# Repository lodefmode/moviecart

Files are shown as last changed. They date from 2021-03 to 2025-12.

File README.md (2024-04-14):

# moviecart
Software and Hardware to create full length color movie + audio cartridges for stock Atari 2600

[How to watch different files:](docs/How_To_Update_Content.txt)

[How to encode your own:](https://www.youtube.com/watch?v=WSy6kNrYDSo&list=PLHJZWs7or3edcvVHDeNzGSZABx2JN1WZH)

Pre-Order Kits at:

https://www.tindie.com/products/lodefmode/moviecart-atari-2600/

September 11 1977
-

Introducing MovieCart.

This revolutionary new product will allow for the first time ever, anyone to experience the joy of the silver screen directly from the comfort of their own home, in stunning digital accuracy.
Boasting an impressive 80 x 192 resolution, 7 bit color and 4 bit monaural audio, begin building your full length feature film library today.*

Technical Specs:

   Two fields are alternated at 60 frames per second.
   Each field consists of a checkerboard pattern of 10 x 262 cells.
   Each cell contains one of 128 colours and is 8 pixels wide by 1 pixel deep.
   This produces an effective resolution of 80 x 262 @ 30 frames per second, with 10 colors per line.
   
   Sound is 4 bit mono produced at 15.720 KHz.

   Joystick controls brightness, volume, and shuttle position.
   Console switches control b/w, ten second rewind and full rewind.

   Each field requires 2.5K of data.
   Each second requires the equivalent of 75.5 Combat cartridges, or over half a million cartridges to produce a full length 2 hour movie.

Thanks,

lodef.mode@gmail.com

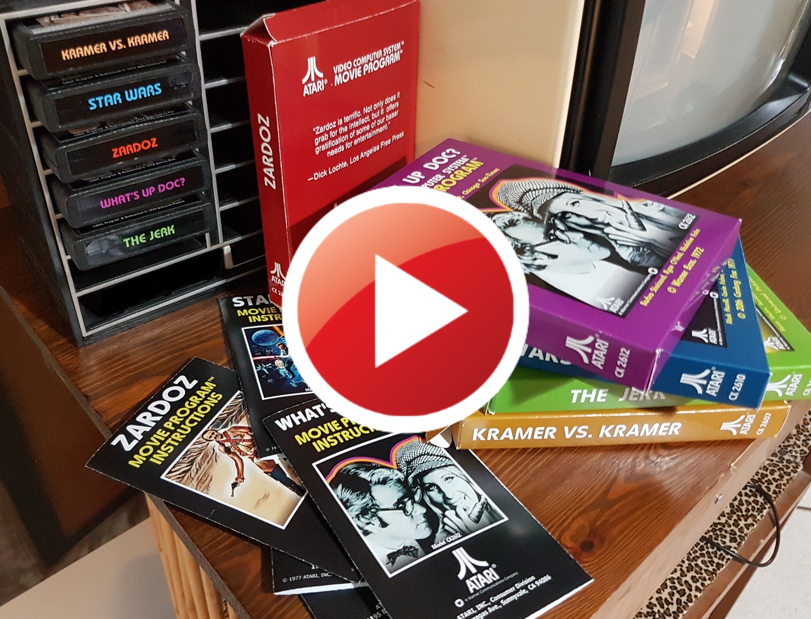
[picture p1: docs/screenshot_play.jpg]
Video (https://www.youtube.com/watch?v=PMp-7_ekibU)


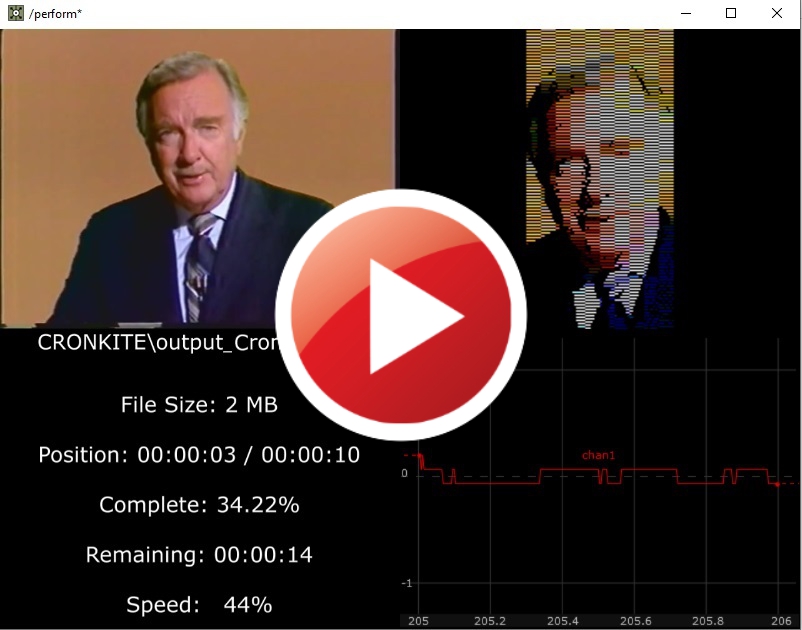
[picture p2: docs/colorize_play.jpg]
Video (https://youtu.be/7HMz1SYGolY)


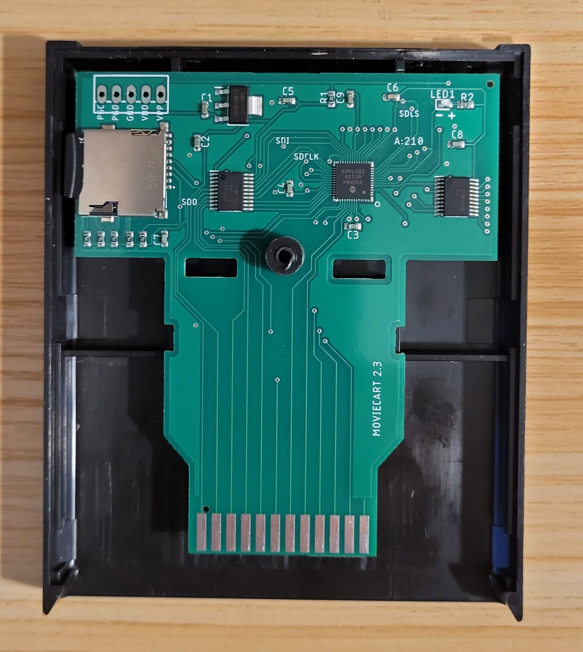
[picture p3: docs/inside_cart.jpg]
Cart

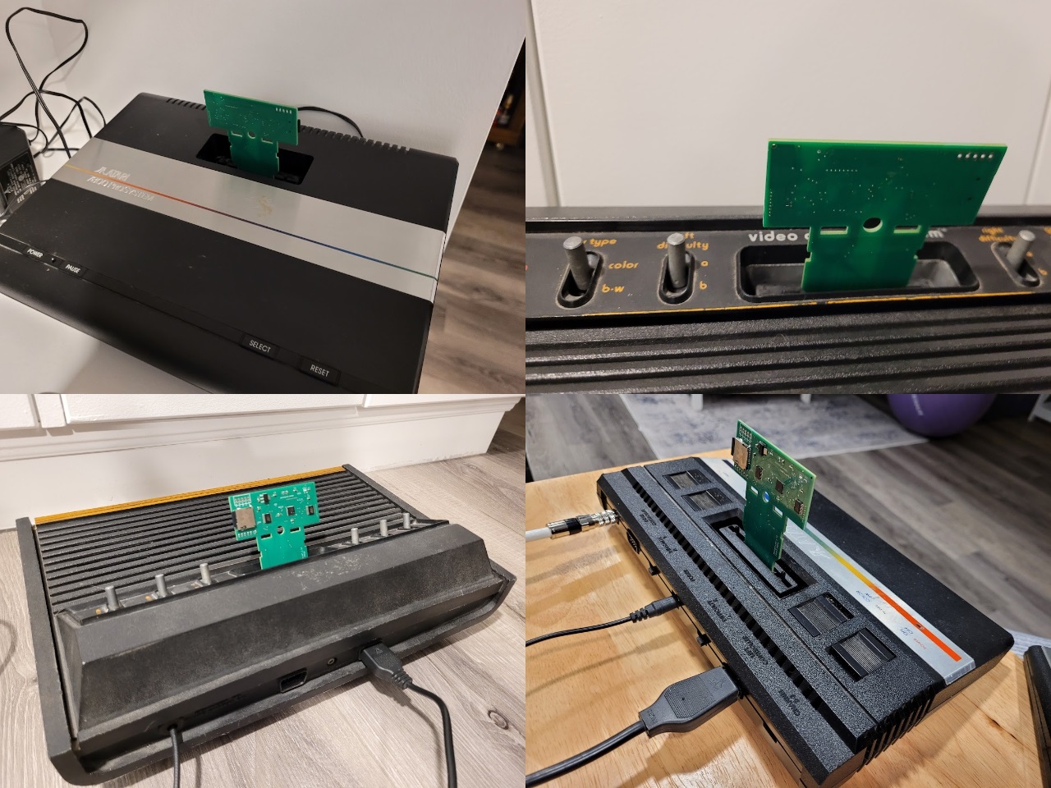
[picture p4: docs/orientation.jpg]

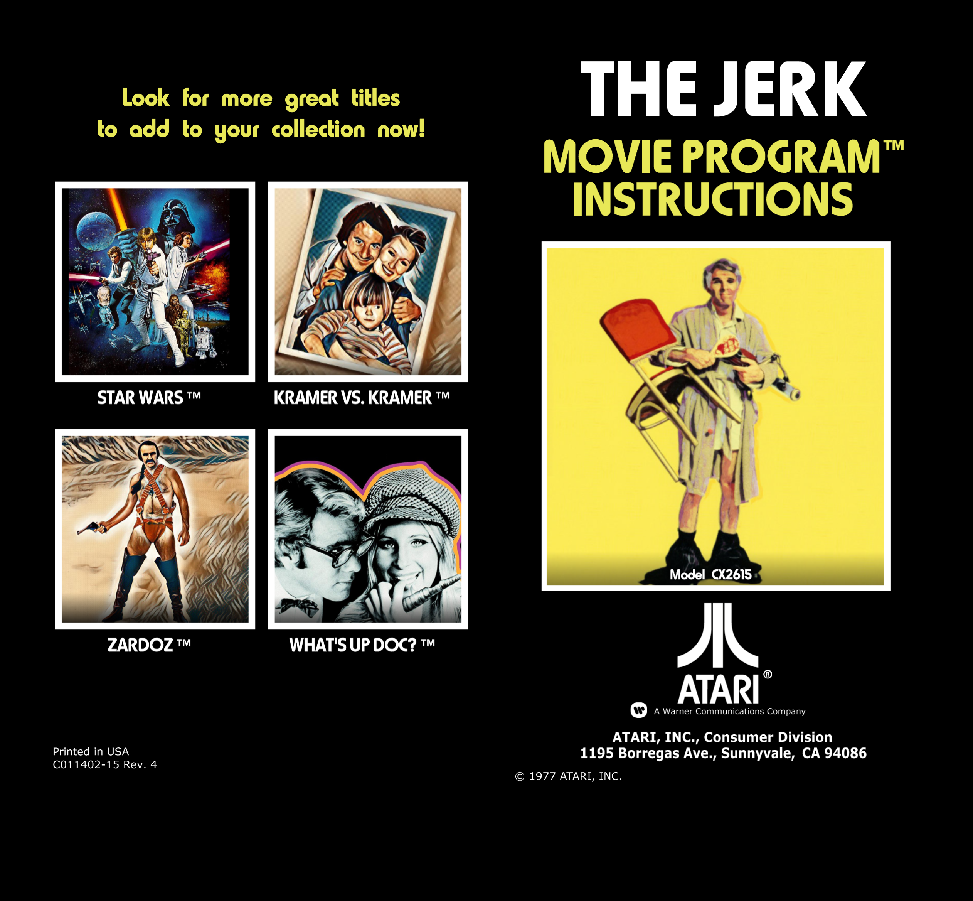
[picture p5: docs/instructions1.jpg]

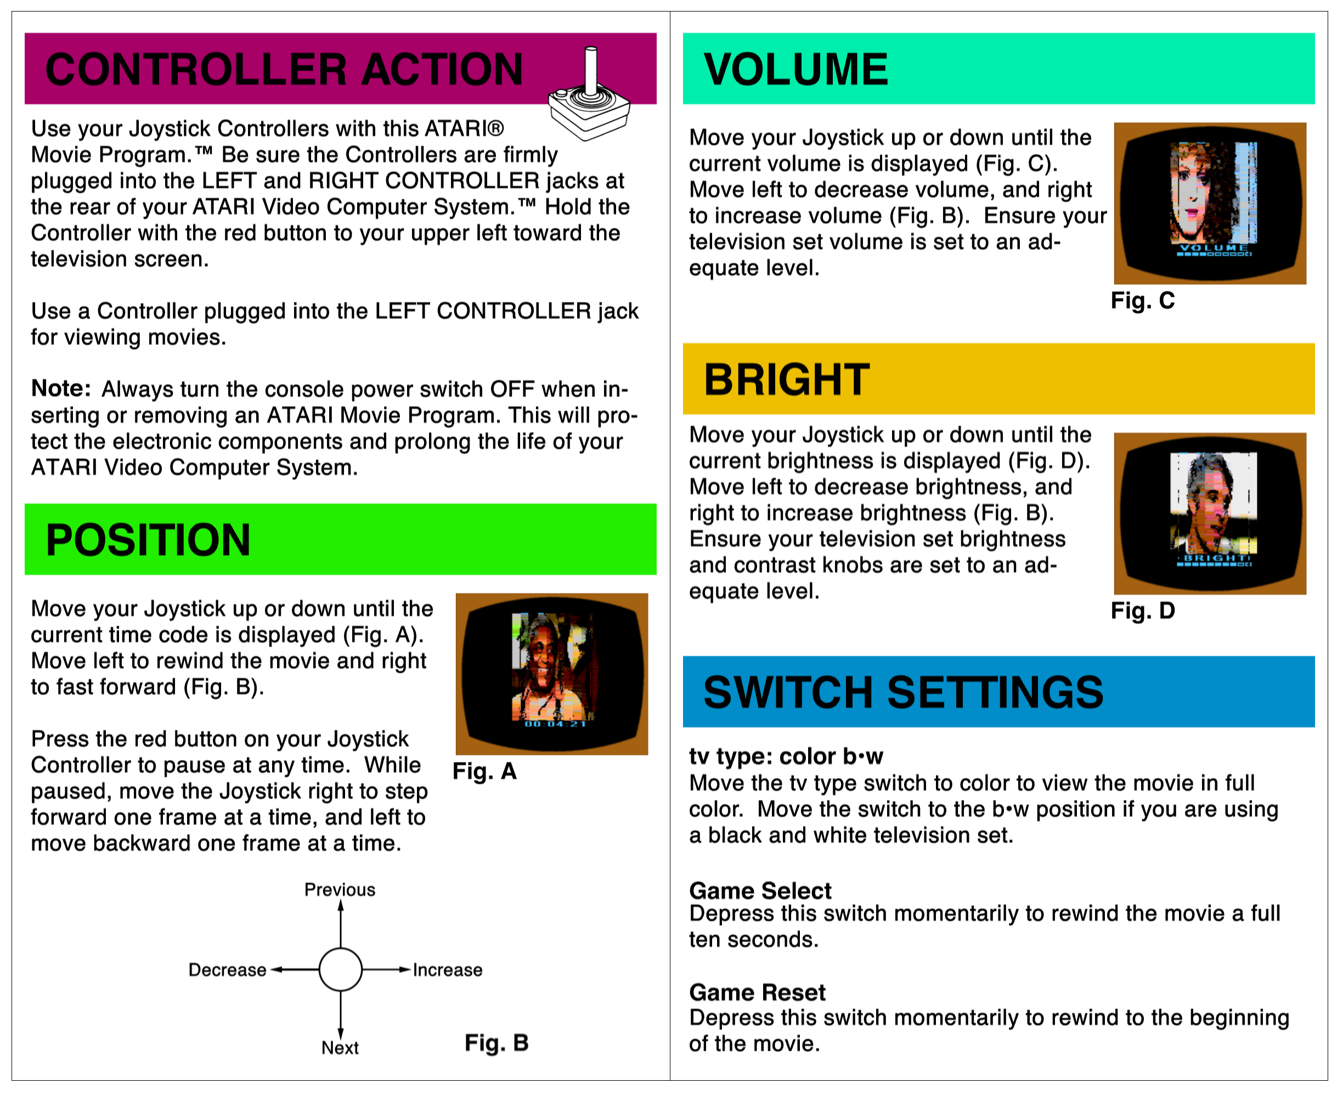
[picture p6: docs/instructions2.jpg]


*Copyright Disclaimer under Section 107 of the copyright act 1976, allowance is made for fair use for purposes such as criticism, comment, news reporting, scholarship, and research. Fair use is a use permitted by copyright statute that might otherwise be infringing. Non-profit, educational or personal use tips the balance in favour of fair use."

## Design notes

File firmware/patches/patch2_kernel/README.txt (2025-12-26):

* WARNING *

This patch is permanent.
And only applies to early MovieCarts (version 1.x from December 2024 and earlier))

Make sure power is not interrupted while the patch is being applied.
This patch fixes writes to ROM as well as being 7800 PAL startup compatible.
It also plays all mvc files sequentially on the SD card automatically, plus other small improvements.

Intstructions:

Note: This requires 2 steps:

Step 1:
With the power off, insert the moviecart with the SD card containing update.frm into the Atari.
Power up the Atari.  If successful the red LED (if visible) on the Moviecart board will flash 2,2  2,2  2,2 etc
(flash flash....pause....flash flash....pause...flash flash... etc)
It should only take a few seconds.

Step 2:
Turn off the Atari
*** REMOVE the SD card, and put it away ***
Turn the Atari back on again.
The LED will now flash 4..4..4..
It should only take a few seconds.

Turn it off and on again. 
Any subsequent powerup will be running the new firmware.
You should see a new title screen with version 2.4 or later.

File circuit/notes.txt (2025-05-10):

Each folder contains a PCB centered around a different package of dsPIC33CK64MC105.
They are otherwise identical.
Note that dsPIC33CK32MC105 is also a suitable drop in replacment at half the program size.

48_TQFP_7x7:
	DSPIC33CK32MC105-I/PT

48_UQFN_6x6:
	DSPIC33CK64MC105-I/M4

Todo:

2.31 
Central hole size:
Still too narrow on some production runs, as drill tolerance varies.
Try increasing slightly.

17/64" drill bit fits perfectly.
3.3734375 mm radius?

currently its:
3.190mm (was 3.175mm)

Around 0.18 mm increase each side.

2.32/2.42:
  hole size increased from 3.19 to 3.373

-----------------

SIKOR version:

Missing 'TV/LABEL SIDE'

special sdcard access version for injection molded offerings:
 -consider moving sd card further to edge to increase access on slotted cart.
   even widen entire top half left/right to reach edge.
 -deepen side tabs toward center to fit
 -consider shortening center post hole to match?
 -consider a double tab piece that glues through rectangular slots for stability.

consider:
  tactile switch to burn/factory reset firmware updates, instead of grounding programming pins

LED is way too bright

Octob 5 2024:

2.42:  change name to 2.52  (2.42 is P/T version)
a couple of vias are too close to paths:
  top left corner of IC, c6

2.52SD
  close vias fixed
  2.52
  'TV SIDE'
  deeper tabs
  SD moved to left edge
  tactile switch to factory reset / restore  (grounding programming pins still works)

2.5SK

  Reshaped for SIKOR carts (5 alignment holes)

2.6SK

  RT3301 reverse mounted factory reset button

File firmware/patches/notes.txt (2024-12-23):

**
** ONLY DO THIS IF ABSOLUTELY NECESSARY AS YOU RISK BRICKING THE MOVIECART **
**

-----------------------------------
INSTALLING A NEW PATCH:
-----------------------------------

Note: Installing a patch will replace any existing patches, so make sure you have the latest.
Select the update.frm file you require and place it on an sd-card by itself with no other files.
Follow the installation instructions in the associated README.txt file for that patch.

-----------------------------------
FACTORY RESET (Remove patch) :
-----------------------------------

* NOTE *  Only some patches are removable, some are permanent.
Please read the notes associated with each patch before applying.

If a patch needs to be removed, use a thin wire with both ends exposed.
A metallic sandwich twist tie, with the paper removed from each end works well.

Remove any SD cards from the MovieCart PCB.
Insert one end through the hole labelled 'PGD' and the other through the hole labelled 'GND'.
These are holes 2 and 3 of a five hole section in the upper left hand side of the MovieCart PCB.
Verify they are labelled 'PGD' and 'GND'.
Verify the ends of the wire aren't making contact with any other points on the PCB.

Insert the MovieCart PCB (with the wire in place) into the Atari, and power up the Atari.
After f;ctory reset, the red LED on the moviecart board will flash the sequence 22..22..22..
(Twice, twice, pause, twice, twice, pause, etc).

Turn off the Atari and remove the wire.
It should now power up as originally delivered.

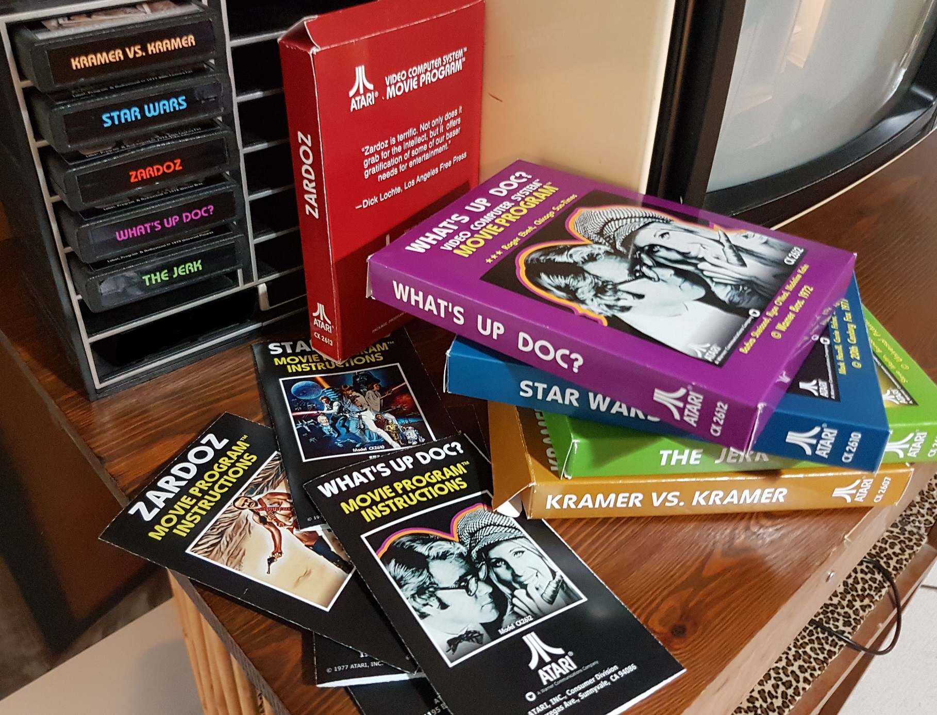
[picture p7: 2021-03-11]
docs/screenshot.jpg

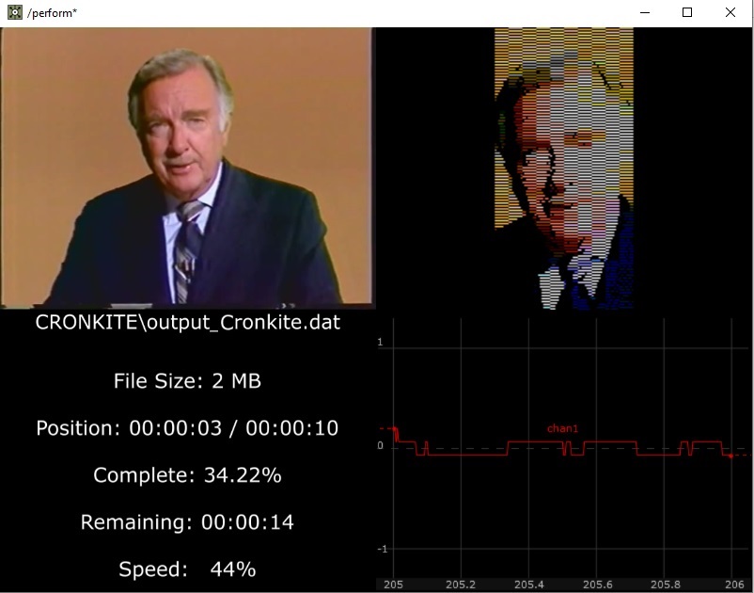
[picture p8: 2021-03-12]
docs/colorize.jpg

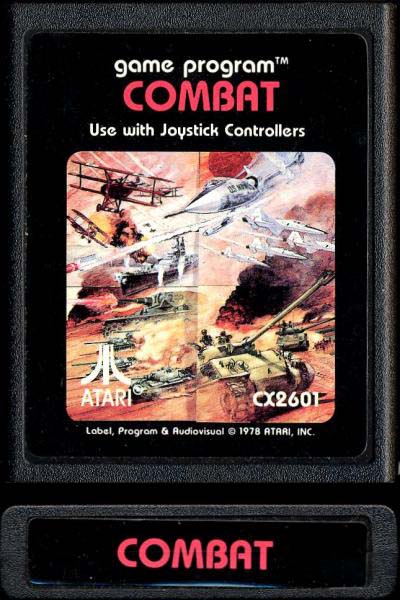
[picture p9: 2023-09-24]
label/resources/combat_reference.jpg

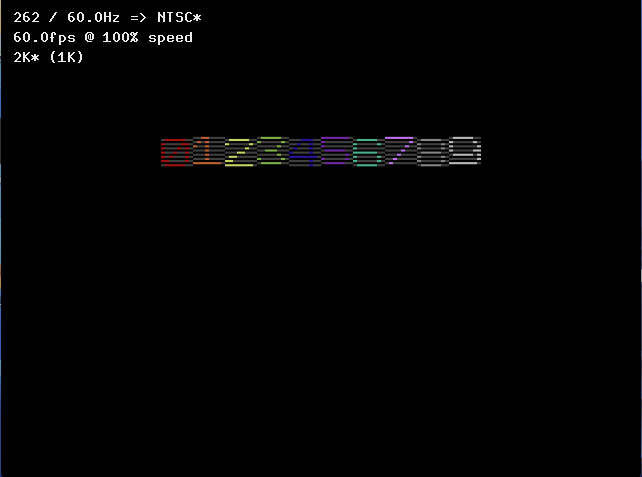
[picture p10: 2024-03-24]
kernel/movie_ntsc.png

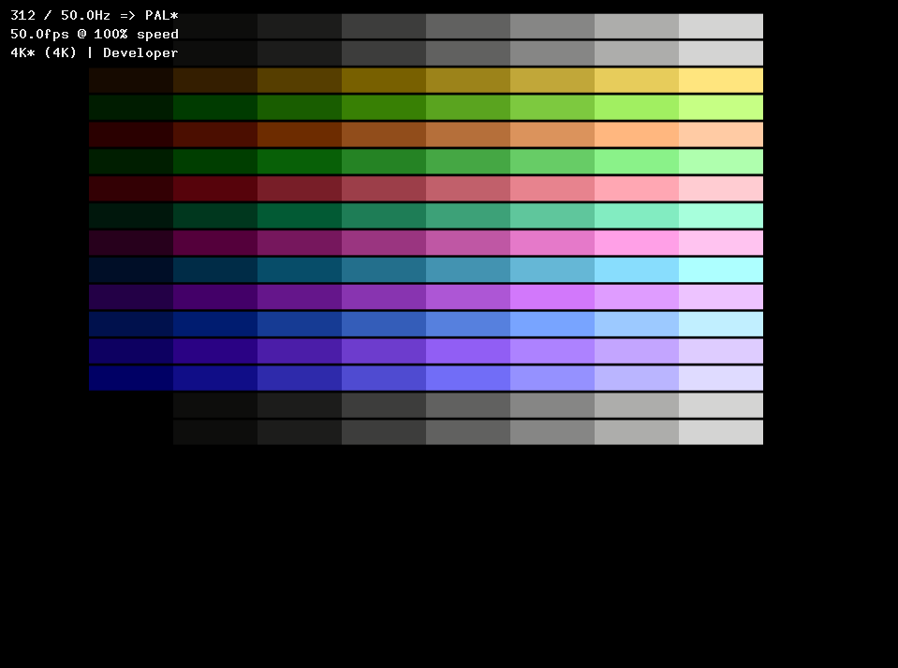
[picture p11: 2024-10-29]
kernel/color_chart/color_chart_pal.png

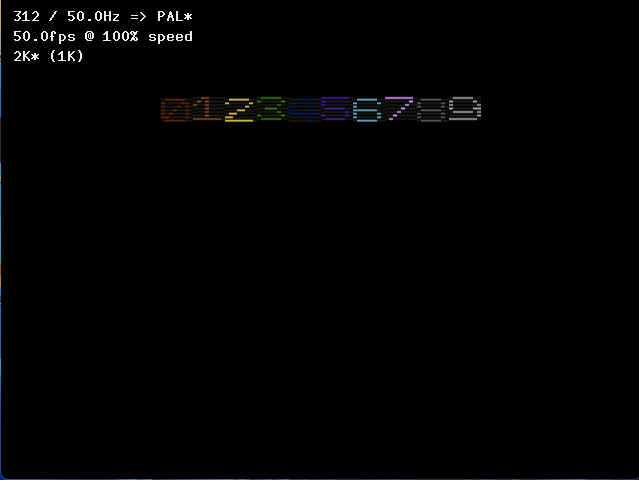
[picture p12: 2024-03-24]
kernel/movie_pal.png

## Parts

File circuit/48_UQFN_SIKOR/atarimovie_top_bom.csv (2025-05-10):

Comment | Designator | Footprint | LCSC Part #
0.1uF | C3 C4 C5 C6 C7 C8 C9 | C0603K
10K | R1 | R0603
10uF | C1 C2 | C0603K
56.2K | R3 R4 R5 R6 R7 | R0603
74LVCH245APW 118 | U2 | SOP65P640X110-20N
74LVCH245APW 118 | U3 | SOP65P640X110-20N
180Ω | R2 | R0603
AMS1117-3.3V | IC1 | SOT229P700X180-4N
CARTRIDGE EDGE | J1 | MED_TABS_SDACCESS
DSPIC33CKXXMC105-X_M4 | U1 | UQFN48_6X6MC_MCH
KT-0603R | LED1 | LEDC1608X70N
RT3301AF260Q | FACTORYRESET | RT3301_EWI
TF-15X15 | J2 | TF15X15

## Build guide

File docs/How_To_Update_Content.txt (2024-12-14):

Updating content:

Your MovieCart should include an sd-card with full length movie on it.
Feel free to put any mvc files on it, including your own.

NOTES:

Best performance is had when the sd-card is freshly formatted before placing the file,
to make forwarding and rewinding smoother.
When formatting an sd-card, it must be FAT32 format.

MovieCart  supports a maximum file size of 4GB.
This translates to around 4 hours of content, so lots of room for most cases.

Early MovieCarts only play the first regular file it finds on the card, so if you have several videos,
they must all be combined before encoding into a single mvc file, or you can update it with the latest
upgrades, including use of the select button to switch between video files.

The files below are zipped for easier download, but they must be UNZIPPED before copying to the sd-card.

# George Romero's classic 1968 thriller, artificially colorized.  
https://drive.google.com/file/d/1Dqfl3UvPZDhm9WUWdjGjJoQySyb--Gze
night_dead_nov23.mvc	 

# Same as above but encoded for PAL format (50 Hz, Atari PAL color format, 242 lines)
https://drive.google.com/file/d/1VxRiaWOX6W1PFH5AJw6gCAL4KVbaCsg3
night_dead_pal.mvc

# PAL60 format (60 Hz but Atari PAL color format, similar to PAL-M in use in Brazil)
https://drive.google.com/file/d/19TsIUbs40wUKhLGFbbGpvHSkD-o-Gi09
nightdead_pal60.mvc

# SECAM format (50 Hz but Atari SECAM color format, very LIMITED color)
https://drive.google.com/file/d/1VsJS2MlWYCcIfghPQl9uj2oBAv7mB7TY
nightdead_secam.mvc

Cheers,
Lodef Mode.

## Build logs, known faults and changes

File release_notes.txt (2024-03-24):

#
# MovieCart Version 2
#
# Rob Bairos
#

Main improvements:

 - Replaced bulky expensive obsolete through-hole IC's with modern SMD components
   which can be fully created by PCB assembly houses.

 - Drop in compatible with Combat cartridges. No cutting / drilling / gluing  required.

 - Micro SD Card uses standard FAT file format, so standard copy / drag-n-drop of files works.
   No longer requires separate utility to prepare card and playback no longer experiences
   random noise.

 - Supports both NTSC and PAL formats.

 - Enhanced video quality utilizing TIA background and playfield colors.

 - Enhanced audio encoding that utilizes error diffusion which introduces constant hiss, but
   eliminates random drop outs and distortion during low volume.

 - Encoding utility redesigned with more features including re-takes.
 
 - Encoding utility GPU accelerated. Speed increase of 2x to 20x depending on video card from previous encoder.
   2 hour movie can be encoded in 30 minutes to 1 hour, instead of a full day.

 - Reliable startup, as boot time is now 0.58 msec from powerup.
   (Flashback 2 starts reading from the cart in 1.52 msec, while Atari 2600 around 25 msec).

#
# Acknowledgements
#

Many thanks to the members of AtariAge for expert advise in kernel development, hardware considerations, user interface and general knowledge.

Andrew Davie
ZackAttack
JetSetIlly
Thomas Jentzch
Shawn
DirtyHairy
Marco J
ZeroPage Homebrew
-^CrossBow^-
swlovinist
TPR
SuperZapperRecharge
Omegamatrix
SpiceWare

and many more.

Night of the Living Dead
	Directed by
		George A. Romero
    Screenplay by
		John Russo
		George A. Romero
	Produced by
		Russell W. Streiner
	    Karl Hardman
	Starring	
		Judith O'Dea
		Duane Jones
		Marilyn Eastman
		Karl Hardman
		Judith Ridley
		Keith Wayne
	Distributed by Contential Distributing
	Released October 1 1968 (Pittburgh, Pennsylvania)

Colorized with De-Oldify python library:
	MIT License
	Copyright (c) 2018 Jason Antic

Busy Street Demo:
	colorize/test/street.mp4
	https://www.pexels.com/video/people-walking-by-on-a-sidewalk-854100/

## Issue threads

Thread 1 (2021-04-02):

BOM Quantities appear incorrect

SteveGuidi, 2021-04-02:
The [BOM](https://github.com/lodefmode/moviecart/blob/main/circuit/Bom_8238251.csv) shows the quantities of each item increasing sequentially from 1 to 9.  Do we need 6 PIC microcontrollers for this project? :)

lodefmode, 2021-04-02:
Hi. That's weird.
Those are likely just the increasing line numbers.
Just one of each thing basically! :)

I'll check it out.

Cheers.
Rob

On Thu, Apr 1, 2021 at 10:38 PM Steve Guidi ***@***.***>
wrote:

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

lodefmode, 2021-04-03:
I've added a new BOM with correct quantities.
They're all singles, except for some 0.1 uF caps, of which there are 3.

Cheers,
Rob.

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

Closed 2021-04-03.

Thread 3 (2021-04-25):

Image area should be flat square

lodefmode, 2021-04-25:
Currently top and bottom lines are incomplete for kernel simplicity.

-_-_-_-_
...
-_-_-_-_

But either each frame should alternate starting with left / right columns, else top and bottom line should be blacked out to create solid square area.

lodefmode, 2021-06-05:
Fixed in 1a52b1d55f7d26042b9a23c34e6d28b

Closed 2021-06-05.

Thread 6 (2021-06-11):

Stepping forward faster than stepping backward.

lodefmode, 2021-06-11:
While paused, stepping forward and back repeatedly does not end on the same frame.
It is stepping forward 3 frames instead of 1.

lodefmode, 2021-06-11:
Fixed with 0857aa450ae3e4ba1bd1e1ec959fbbb

Closed 2021-06-11.

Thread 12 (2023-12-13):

broken crop in GUI

andrew-davie, 2023-12-13:
Loaded the crop tab, then clicked in the visual crop box window. Held button and moved mouse left. Crop changed to -0.4, etc, and I no longer have any ability to move the crop box, and the values are set to read only. So it's broken!  Image shows state where I cannot modify crop values.  I really dislike the enforcement of read-only on values I may want to change manually.

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

lodefmode, 2023-12-16:
You can always press the 'Reset Crop' button, however latest is now has editable crop fields again.
Fix #81e4da7d79cc6d84c35776ca27ed072c797e86d8

Closed 2023-12-16.

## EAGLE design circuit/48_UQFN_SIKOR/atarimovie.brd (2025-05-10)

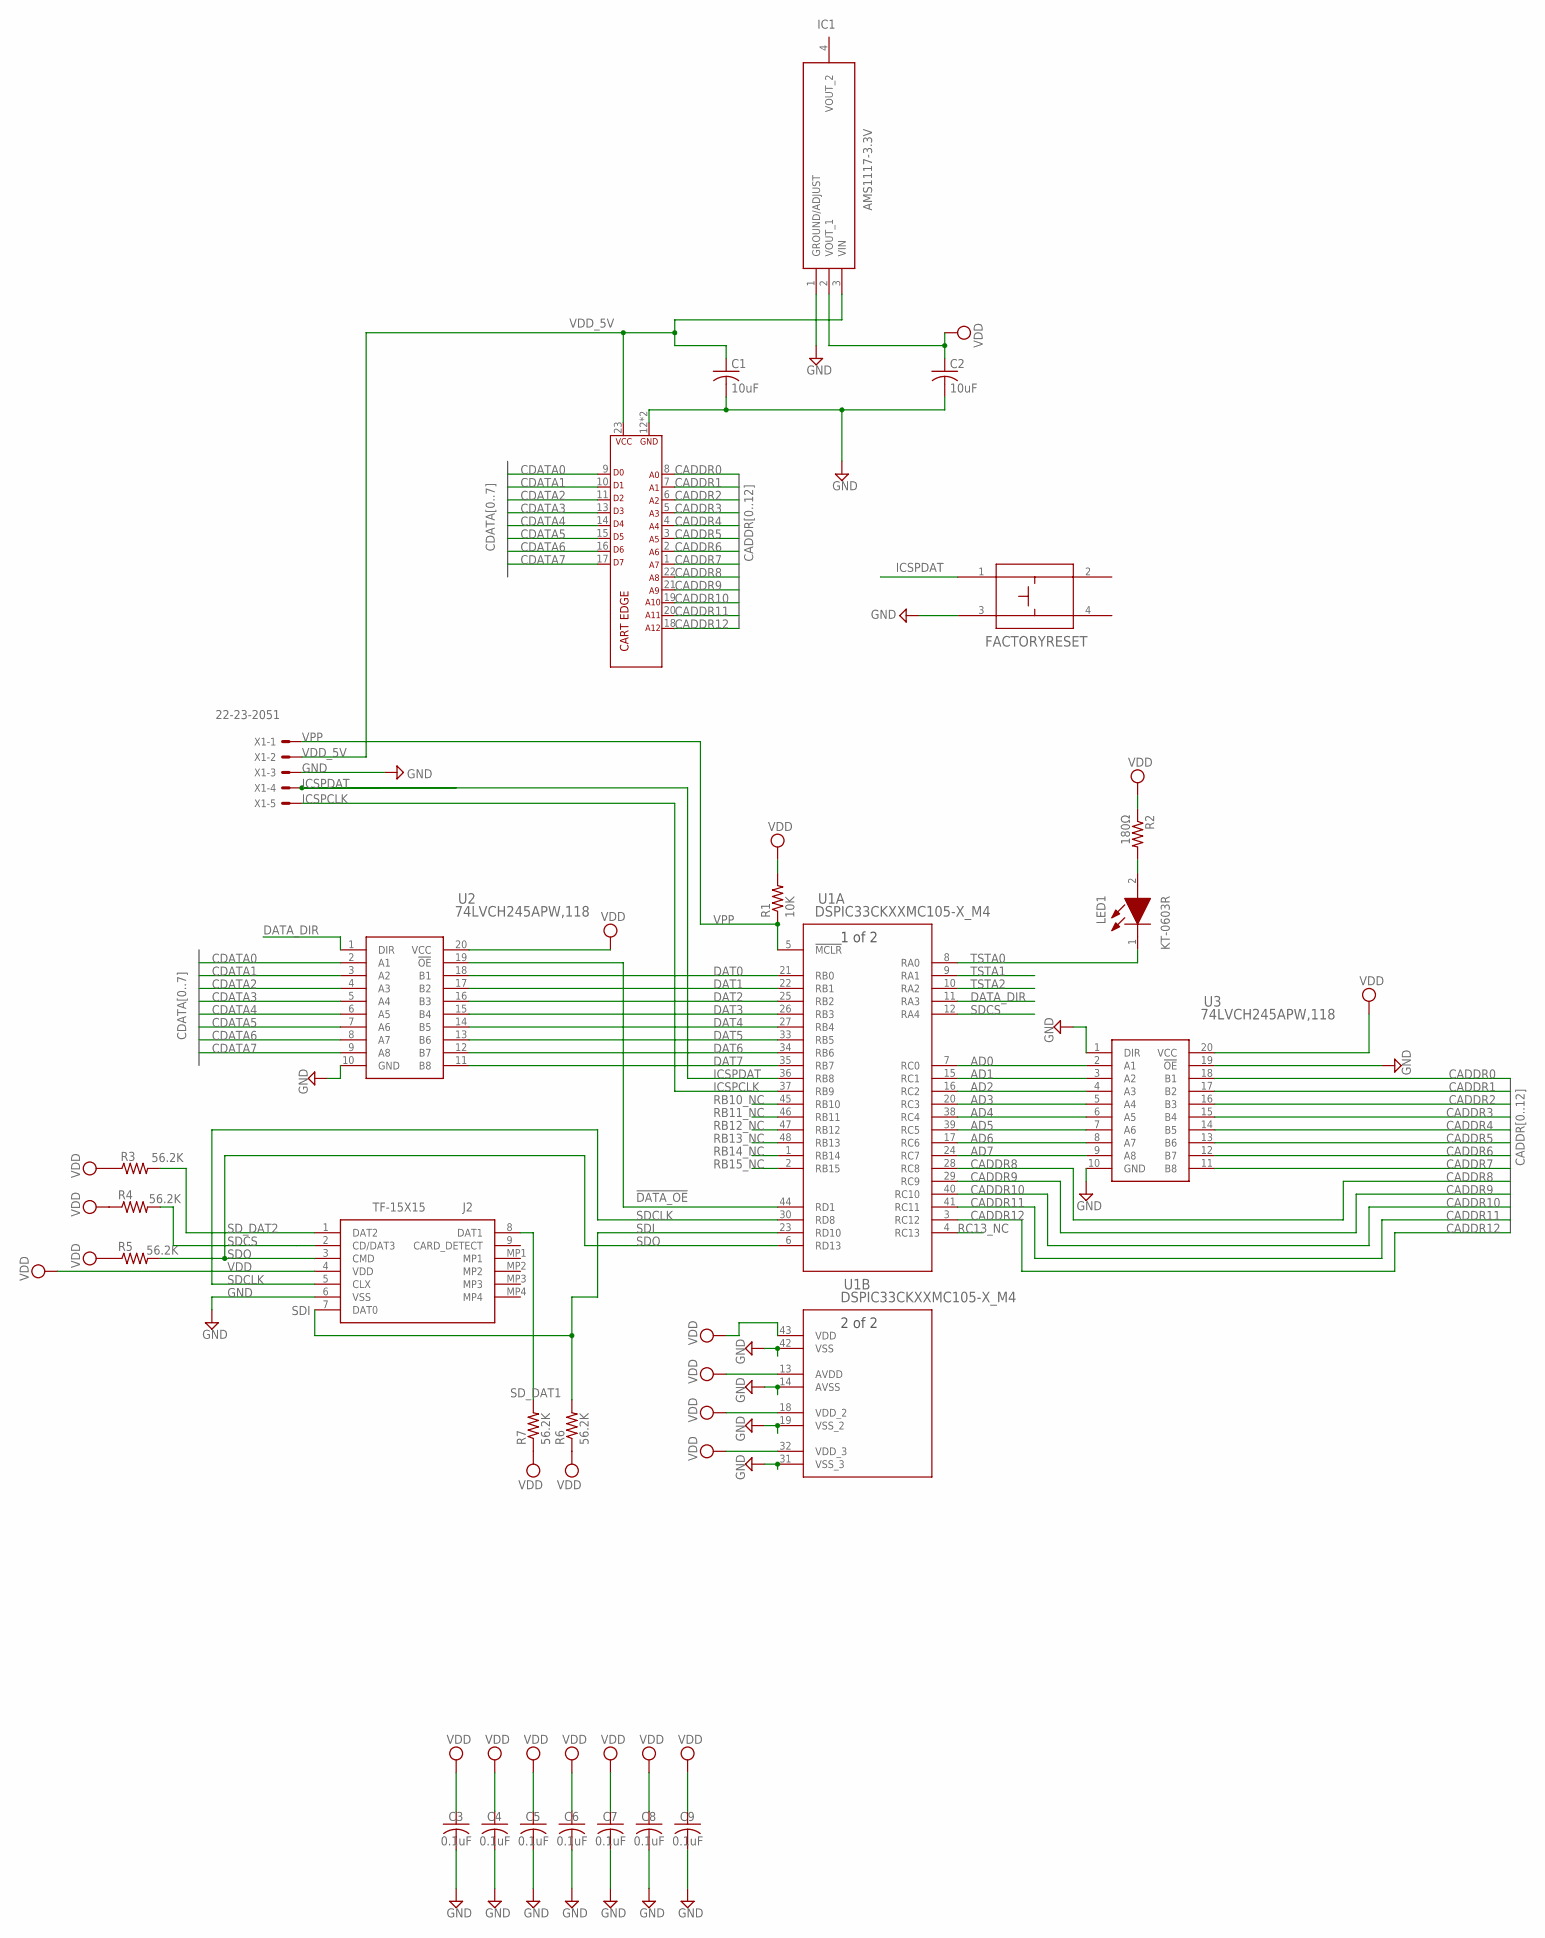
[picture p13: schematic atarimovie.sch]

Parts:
C1, C2: 10uF; C0603K
C3, C4, C5, C6, C7, C8, C9: 0.1uF; C0603K
FACTORYRESET: RT3301AF260Q; RT3301_EWI
IC1: AMS1117-3.3V; SOT229P700X180-4N
J1: CARTRIDGE EDGE; MED_TABS_SDACCESS
J2: TF-15X15; TF15X15
LED1: KT-0603R; LEDC1608X70N
R1: 10K; R0603
R2: 180Ω; R0603
R3, R4, R5, R6, R7: 56.2K; R0603
U1: DSPIC33CKXXMC105-X_M4; UQFN48_6X6MC_MCH
U2, U3: 74LVCH245APW,118; SOP65P640X110-20N
X1: 22-23-2051

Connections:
!DATA_OE!: U1.44 (RD1), U2.19 (!OE)
AD0: U1.7 (RC0), U3.2 (A1)
AD1: U1.15 (RC1), U3.3 (A2)
AD2: U1.16 (RC2), U3.4 (A3)
AD3: U1.20 (RC3), U3.5 (A4)
AD4: U1.38 (RC4), U3.6 (A5)
AD5: U1.39 (RC5), U3.7 (A6)
AD6: U1.17 (RC6), U3.8 (A7)
AD7: U1.24 (RC7), U3.9 (A8)
CADDR0: J1.8 (A0), U3.18 (B1)
CADDR1: J1.7 (A1), U3.17 (B2)
CADDR2: J1.6 (A2), U3.16 (B3)
CADDR3: J1.5 (A3), U3.15 (B4)
CADDR4: J1.4 (A4), U3.14 (B5)
CADDR5: J1.3 (A5), U3.13 (B6)
CADDR6: J1.2 (A6), U3.12 (B7)
CADDR7: J1.1 (A7), U3.11 (B8)
CADDR8: J1.22 (A8), U1.28 (RC8)
CADDR9: J1.21 (A9), U1.29 (RC9)
CADDR10: J1.19 (A10), U1.40 (RC10)
CADDR11: J1.20 (A11), U1.41 (RC11)
CADDR12: J1.18 (A12), U1.3 (RC12)
CDATA0: J1.9 (D0), U2.2 (A1)
CDATA1: J1.10 (D1), U2.3 (A2)
CDATA2: J1.11 (D2), U2.4 (A3)
CDATA3: J1.13 (D3), U2.5 (A4)
CDATA4: J1.14 (D4), U2.6 (A5)
CDATA5: J1.15 (D5), U2.7 (A6)
CDATA6: J1.16 (D6), U2.8 (A7)
CDATA7: J1.17 (D7), U2.9 (A8)
DAT0: U1.21 (RB0), U2.18 (B1)
DAT1: U1.22 (RB1), U2.17 (B2)
DAT2: U1.25 (RB2), U2.16 (B3)
DAT3: U1.26 (RB3), U2.15 (B4)
DAT4: U1.27 (RB4), U2.14 (B5)
DAT5: U1.33 (RB5), U2.13 (B6)
DAT6: U1.34 (RB6), U2.12 (B7)
DAT7: U1.35 (RB7), U2.11 (B8)
DATA_DIR: U1.11 (RA3), U2.1 (DIR)
GND: C1.2, C2.2, C3.2, C4.2, C5.2, C6.2, C7.2, C8.2, C9.2, FACTORYRESET.3, IC1.1 (GROUND/ADJUST), J1.12 (GND), J1.24 (GND), J2.6 (VSS), U1.14 (AVSS), U1.19 (VSS_2), U1.31 (VSS_3), U1.42 (VSS), U2.10 (GND), U3.1 (DIR), U3.10 (GND), U3.19 (!OE), X1.3
ICSPCLK: U1.37 (RB9), X1.5
ICSPDAT: FACTORYRESET.1, U1.36 (RB8), X1.4
unnamed: LED1.2 (A), R2.2
RB10_NC: U1.45 (RB10)
RB11_NC: U1.46 (RB11)
RB12_NC: U1.47 (RB12)
RB13_NC: U1.48 (RB13)
RB14_NC: U1.1 (RB14)
RB15_NC: U1.2 (RB15)
RC13_NC: U1.4 (RC13)
SDCLK: J2.5 (CLX), U1.30 (RD8)
SDCS: J2.2 (CD/DAT3), R4.2, U1.12 (RA4)
SDI: J2.7 (DAT0), R6.2, U1.23 (RD10)
SDO: J2.3 (CMD), R5.2, U1.6 (RD13)
SD_DAT1: J2.8 (DAT1), R7.2
SD_DAT2: J2.1 (DAT2), R3.2
TSTA0: LED1.1 (K), U1.8 (RA0)
TSTA1: U1.9 (RA1)
TSTA2: U1.10 (RA2)
VDD: C2.1, C3.1, C4.1, C5.1, C6.1, C7.1, C8.1, C9.1, IC1.2 (VOUT_1), J2.4 (VDD), R1.2, R2.1, R3.1, R4.1, R5.1, R6.1, R7.1, U1.13 (AVDD), U1.18 (VDD_2), U1.32 (VDD_3), U1.43 (VDD), U2.20 (VCC), U3.20 (VCC)
VDD_5V: C1.1, IC1.3 (VIN), J1.23 (VCC), X1.2
VPP: R1.1, U1.5 (!MCLR), X1.1

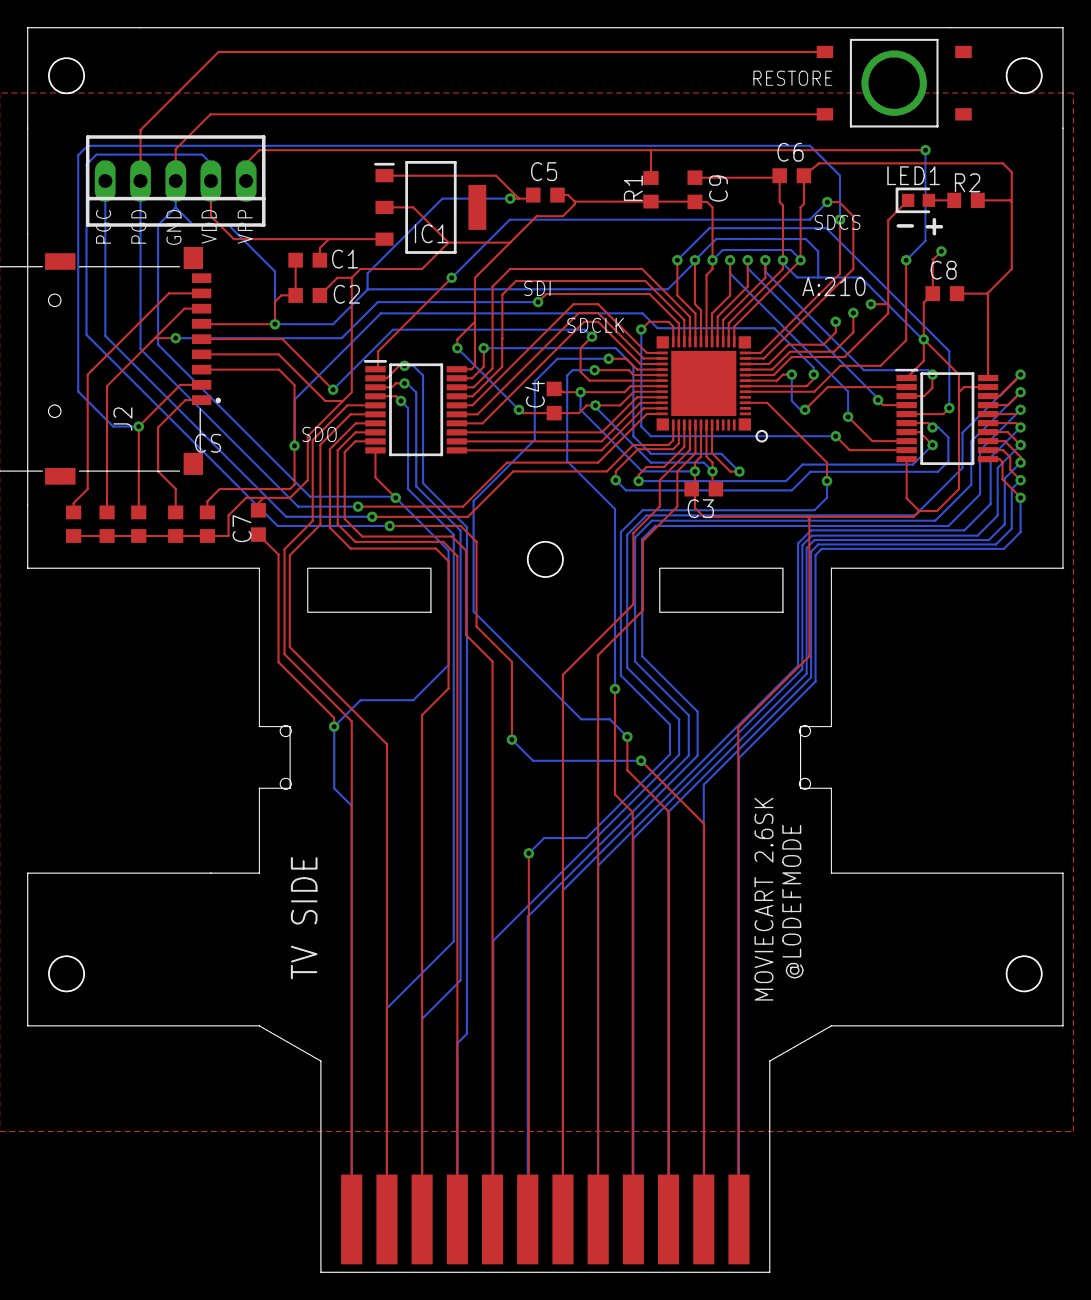
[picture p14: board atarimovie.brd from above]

Board: 2 copper layers, 74.7 x 89.8 mm, 25 parts (1 on the bottom side), 53 nets.

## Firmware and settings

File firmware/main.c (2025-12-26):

/**
  Generated main.c file from MPLAB Code Configurator

  @Company
    Microchip Technology Inc.

  @File Name
    main.c

  @Summary
    This is the generated main.c using PIC24 / dsPIC33 / PIC32MM MCUs.

  @Description
    This source file provides main entry point for system initialization and application code development.
    Generation Information :
        Product Revision  :  PIC24 / dsPIC33 / PIC32MM MCUs - 1.170.0
        Device            :  dsPIC33CK64MC105
    The generated drivers are tested against the following:
        Compiler          :  XC16 v1.61
        MPLAB 	          :  MPLAB X v5.45
*/

/*
    (c) 2020 Microchip Technology Inc. and its subsidiaries. You may use this
    software and any derivatives exclusively with Microchip products.

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
    IN NO EVENT WILL MICROCHIP BE LIABLE FOR ANY INDIRECT, SPECIAL, PUNITIVE,
    INCIDENTAL OR CONSEQUENTIAL LOSS, DAMAGE, COST OR EXPENSE OF ANY KIND
    WHATSOEVER RELATED TO THE SOFTWARE, HOWEVER CAUSED, EVEN IF MICROCHIP HAS
    BEEN ADVISED OF THE POSSIBILITY OR THE DAMAGES ARE FORESEEABLE. TO THE
    FULLEST EXTENT ALLOWED BY LAW, MICROCHIP'S TOTAL LIABILITY ON ALL CLAIMS IN
    ANY WAY RELATED TO THIS SOFTWARE WILL NOT EXCEED THE AMOUNT OF FEES, IF ANY,
    THAT YOU HAVE PAID DIRECTLY TO MICROCHIP FOR THIS SOFTWARE.

    MICROCHIP PROVIDES THIS SOFTWARE CONDITIONALLY UPON YOUR ACCEPTANCE OF THESE
    TERMS.
*/

/**
  Section: Included Files
*/

#include <string.h> // memset

#include "mcc_generated_files/system.h"
#include "mcc_generated_files/pin_manager.h"
#include "mcc_generated_files/spi1.h"
#include "mcc_generated_files/memory/flash.h"
#include "mcc_generated_files/interrupt_manager.h"


#if 1
#include "mcc_generated_files/clock.h"
#define FOSC    (CLOCK_SystemFrequencyGet())
#define FCY     (CLOCK_InstructionFrequencyGet())
#include <libpic30.h>
#endif


__attribute__((section(".newcode"),space(prog))) void main2(void);


#include "pff.h"
#include "core.h"
#include "update.h"

void flash_led(uint8_t num);
void coreInfoToState();
void resetNewCode();

__attribute__((section(".magicIDSection"),space(prog))) const uint32_t magicID = 0x1357c0de;
__attribute__((section(".firmwareIDSection"),space(prog))) const uint32_t firmwareID = 0x000204;

__attribute__((section(".resetNewCodeAndFlashSection"),space(prog)))
void
resetNewCodeAndFlash(void)
{
	resetNewCode();
	while(1)
	{
		flash_led(0);
		flash_led(1);
		flash_led(2);
	}
}

void
flash_led(uint8_t num)
{
	uint8_t	i;

	for (i=0; i<num; i++)
    {
		TESTA0_LOW			// on
         __delay_ms(150);
        
		TESTA0_HIGH			// off
        __delay_ms(150);
    }
	
	if (!num)
		__delay_ms(500);

	__delay_ms(500);
}

// can be used for debugging
// 155000 Bits/sec
// 8 bits per transfer (standard)
// 2 stop bits
// no parity bit (standard)
// least significant bit sent first (standard)
// non inverted (standard)

void
serialLED(uint8_t v)
{
    uint16_t    i, j;

    // start bit
    for (i=0; i<24; i++)
		TESTA0_LOW
        
    for (j=0; j<8; j++)
    {
        if (v & (1<<j))
        {
            for (i=0; i<24; i++)
            {
				TESTA0_HIGH
            }
        }
        else
        {
            for (i=0; i<24; i++)
            {
				TESTA0_LOW
            }
        }        
    }

    // stop bit
    for (i=0; i<24*2; i++)
		TESTA0_HIGH
}

/*
                         Main application
 */


extern struct coreInfo			r_coreInfo;
extern struct fileSystemInfo	fsInfo;
extern struct queueInfo			qinfo;

extern uint16_t __attribute__((space(prog))) TitleGraph1[];
extern uint16_t __attribute__((space(prog))) TitleColor1[];
extern uint16_t __attribute__((space(prog))) TitleBackColor1[];

extern uint16_t __attribute__((space(prog))) TitleGraph2[];
extern uint16_t __attribute__((space(prog))) TitleColor2[];
extern uint16_t __attribute__((space(prog))) TitleBackColor2[];


extern void updateInit();


__attribute__((section(".stateVars"))) struct stateVars		state;
__attribute__((section(".mr_buffer1"))) uint8_t mr_buffer1[FIELD_SIZE];
__attribute__((section(".mr_buffer2")))uint8_t mr_buffer2[FIELD_SIZE];

// Allocate and reserve a page of flash for this test to use.  The compiler/linker will reserve this for data and not place any code here.
//static __prog__  uint8_t flashTestPage[FLASH_ERASE_PAGE_SIZE_IN_PC_UNITS] __attribute__((space(prog),aligned(FLASH_ERASE_PAGE_SIZE_IN_PC_UNITS)));

void
copyFromFlash(uint8_t *dst, uint32_t src, int size)
{
	while (size > 0)
	{
		uint32_t read_data = FLASH_ReadWord24(src);

		*dst++ = (read_data & 0x0000ff) >> 0;
		*dst++ = (read_data & 0x00ff00) >> 8;
		*dst++ = (read_data & 0xff0000) >> 16;

		src += 2;
		size -= 3;
	}
}

void
resetNewCode()
{
    FLASH_Unlock(FLASH_UNLOCK_KEY);
    FLASH_ErasePage((uint16_t)&main2);
    FLASH_Lock();
}

void
handleFirmwareUpdate()
{
	// is this an udpate file?
	if (memcmp(fsInfo.name, "UPDATE  FRM", 11) != 0)
        return;
    
	INTERRUPT_GlobalDisable();

	// first pass write,
	// second pass confirm

	for (uint8_t i=0; i<2; i++)
	{
		if (i == 0)
			FLASH_Unlock(FLASH_UNLOCK_KEY);

		uint32_t	block = 0;	// blocks
		uint32_t	dst = (uint16_t)&main2;
		uint32_t	erased_pc = dst;

		int32_t	size = fsInfo.fsize;
		while(size > 0)
		{
			while (!pf_seek_block(block))
			{
				flash_led(2);
			}

			uint32_t*	buf = (uint32_t*)mr_buffer1;
			pf_read_block(mr_buffer1);


			int32_t	remaining_chunk = 512;

			while (remaining_chunk > 0)
			{
				uint32_t a = buf[0];
				uint32_t b = buf[1];

				// write
				if (i == 0)
				{
					// make some space
					while (erased_pc < (dst + 4))
					{
						if (!FLASH_ErasePage(erased_pc))
							goto bad;
						erased_pc += FLASH_ERASE_PAGE_SIZE_IN_PC_UNITS;	// 2K
					}
					
					if (!FLASH_WriteDoubleWord24(dst, a, b))
						goto bad;
				}
				else // confirm
				{
					if (FLASH_ReadWord24(dst+0) != a)
						goto bad;

					if (FLASH_ReadWord24(dst+2) != b)
						goto bad;
				}

				dst  += 4;
				buf  += 2;
				
				remaining_chunk -= 8;
				size -= 8;
				
				// may happen for short blocks
				if (size <= 0)
					break;

				// overwriting configuration memory?
				if (dst >= 0xAF00)
					goto bad;
			}

			block += 1; // next 512 bytes
		};

		if (i == 0)
			FLASH_Lock();
	}


//good:

	while(1)
	{
		flash_led(0);
		flash_led(1);
		flash_led(3);	// good
	}

bad:

	// back to default
	resetNewCode();

	while(1)
	{
		flash_led(0);
		flash_led(2);
		flash_led(1);	// bad
	}
}

void
setupTitle()
{
	// setup frame headers quickly
	r_coreInfo.frameInfo.buffer = mr_buffer1;
	r_coreInfo.mr_frameInfo1.buffer = mr_buffer1;
	r_coreInfo.mr_frameInfo2.buffer = mr_buffer2;

	frameInitTitle(&r_coreInfo.frameInfo, 0);
	frameInitTitle(&r_coreInfo.mr_frameInfo1, 0);
	frameInitTitle(&r_coreInfo.mr_frameInfo2, 1);

	// zero everything since height may change
	memset(mr_buffer1, 0, sizeof(mr_buffer1));
	memset(mr_buffer2, 0, sizeof(mr_buffer2));

	// copy title screen over

	int	lineTotal = r_coreInfo.mr_frameInfo1.visibleLines * 5;

	copyFromFlash(r_coreInfo.mr_frameInfo1.graphBuf, (uint16_t)TitleGraph1, lineTotal);
	copyFromFlash(r_coreInfo.mr_frameInfo1.colorBuf, (uint16_t)TitleColor1, lineTotal);
	copyFromFlash(r_coreInfo.mr_frameInfo1.colorBKBuf, (uint16_t)TitleBackColor1, r_coreInfo.mr_frameInfo1.visibleLines);

	copyFromFlash(r_coreInfo.mr_frameInfo2.graphBuf, (uint16_t)TitleGraph2, lineTotal);
	copyFromFlash(r_coreInfo.mr_frameInfo2.colorBuf, (uint16_t)TitleColor2, lineTotal);
	copyFromFlash(r_coreInfo.mr_frameInfo2.colorBKBuf, (uint16_t)TitleBackColor2, r_coreInfo.mr_frameInfo2.visibleLines);

}

void
setupDisk()
{
	// now load the file
	while (!pf_mount())
	{
		flash_led(4);
	}

	// first available regular file
	state.io_frameNumber = 1;
	state.io_bits &= ~STATE_PLAYING;
	while (!pf_open_file(&state.i_numFrames, 1))
	{
		flash_led(3);
	}

	SPI1_HighSpeed();
}

void
prepareNextFrame()
{
	struct frameInfo*	fInfo;

	if (r_coreInfo.mr_bufferIndex)
		fInfo = &r_coreInfo.mr_frameInfo1;
	else
		fInfo = &r_coreInfo.mr_frameInfo2;
	
	uint8_t*	dst = fInfo->buffer;
	uint32_t	offset = (state.io_frameNumber * FIELD_NUM_BLOCKS);

	while (!pf_seek_block(offset))
	{
		flash_led(4);
	}

	// first block
	pf_read_block(dst);
	dst += 512;
	frameInit(fInfo);
	
	// remaining blocks
	int nb = fInfo->numBlocks - 1;
	while(nb)
	{
		pf_read_block(dst);
		dst += 512;
		nb--;
	}
				
	updateBuffer(&state, fInfo);
}

void
waitEndFrame()
{
	// wait for transition
	TESTA2_LOW
	while (!r_coreInfo.mr_endFrame)
	{

	}
	r_coreInfo.mr_endFrame = 0;
	TESTA2_HIGH
}

void
runTitle()
{
	uint16_t		m_titleFrame = 300; // 5 seconds

	// sample the file to see if title should be PAL format etc
	state.io_frameNumber = 1;
	uint32_t	offset = (state.io_frameNumber * FIELD_NUM_BLOCKS);

	while (!pf_seek_block(offset))
	{
		flash_led(2);
		flash_led(3);
	}

	// line up to the right buffer we'll be using
	// so its not visible on screen

	waitEndFrame();
	if (!r_coreInfo.mr_bufferIndex)
		waitEndFrame();

	// just read the first block into the colorBuf, as we don't have spare ram
	struct frameInfo	fInfo;
	fInfo.buffer = r_coreInfo.mr_frameInfo1.colorBuf;
	pf_read_block(fInfo.buffer);

	frameInit(&fInfo);
	uint8_t	fileVis = fInfo.visibleLines;

	// restore it as quickly as possible
	copyFromFlash(r_coreInfo.mr_frameInfo1.colorBuf, (uint16_t)TitleColor1, 512);


	// now override title to file height

	int				diff = fileVis - r_coreInfo.mr_frameInfo1.visibleLines;

	r_coreInfo.mr_frameInfo1.visibleLines += diff;
	r_coreInfo.mr_frameInfo2.visibleLines += diff;

	r_coreInfo.mr_frameInfo1.totalLines += diff;
	r_coreInfo.mr_frameInfo2.totalLines += diff;

	while(m_titleFrame--)
	{
		waitEndFrame();

		coreInfoToState();
		updateTransport(&state);

		// if reset button pressed skip title frame
		if (state.io_bits & STATE_PLAYING)
			break;
	}

}

void
checkSelectVideo(int* which)
{
	// if at end, or select pressed go to next video
	if ((state.io_bits & STATE_END) || ((state.i_swchb & 0x02) && !(r_coreInfo.mr_swchb & 0x02)))
	{
        state.io_bits &= ~STATE_END;

		(*which)++;
		while (!pf_open_file(&state.i_numFrames, (*which)))
		{
			(*which) = 1;
		}

		// reset rewind cache
		qinfo.head = 0;
		for (int i=0; i<QUEUE_SIZE; i++)
		{
			qinfo.block[i] = -1;
			qinfo.clust[i] = -1;
		}

		state.io_frameNumber = 1;
		state.io_bits |= STATE_PLAYING;

		// go to black
		memset(mr_buffer1, 0, sizeof(mr_buffer1));
		memset(mr_buffer2, 0, sizeof(mr_buffer2));

		// debounce
		for (int i=0; i<30; i++)
			waitEndFrame();
	}

	coreInfoToState();
}


void
runFrameLoop()
{
	uint_fast8_t	t = 0;
	int 			which = 1;

	state.io_frameNumber = 1;
	state.io_bits =  STATE_PLAYING;

	while(1)
	{
		waitEndFrame();

		t++;
        if (t == 60)
        {
			TESTA0_LOW
            t = 0;
        }
        else
        {
			TESTA0_HIGH
        }
        
		checkSelectVideo(&which);

		updateTransport(&state);
		prepareNextFrame();
	}
}


int
main(void)
{    
    // initialize the device
    SYSTEM_Initialize();


    // check for new code
    {
        uint32_t newCode = FLASH_ReadWord24((uint16_t)&main2);    
        if (newCode != 0xFFFFFF && newCode != 0x60000)
        {
			// check for factory reset RB8(PGD) RB9(PGC) have WPU enabled
			if (!_RB8 && _RB9)
			{
				resetNewCodeAndFlash();
			}
			else
			{
				const void* address = &main2 + 2;
				goto *address;
			}
        }
    }
    

    // safe to start (will be in reset several times)
	coreInit();

#if 0 // Use this to test measure startup time
    uint_fast8_t i, j;
    for (i=10;i>0; i--)
    {
        for (int j=10; j>0; j--)
            TESTA2_HIGH
        for (int j=10; j>0; j--)
            TESTA2_LOW    
    }
#endif

	setupTitle();
	setupDisk();
	handleFirmwareUpdate();
	updateInit();
	runTitle();
	runFrameLoop();
}

void
coreInfoToState()
{
	state.i_swcha = r_coreInfo.mr_swcha;
	state.i_swchb = r_coreInfo.mr_swchb;
	state.i_inpt4 = r_coreInfo.mr_inpt4;
	state.i_inpt5 = r_coreInfo.mr_inpt5;

	// merge left+right direction + fire button together for either joystick usage
	// for systems that have bad controller ports
	
	state.i_swcha = ((state.i_swcha << 4) | (state.i_swcha & 0x0f)) & state.i_swcha;
	state.i_inpt4 &= r_coreInfo.mr_inpt5;
}

// new updates placed here
// must be page_erase aligned
__attribute__((section(".newcode"),space(prog))) void main2(void)
{
#if 0
	// add these always since its not clear if we need to jump to main or main+2
    asm("nop");
    asm("nop");
#endif

}


/**
 End of File
*/

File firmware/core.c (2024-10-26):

#include "pff.h"
#include "core.h"

#include "mcc_generated_files/system.h"
#include "mcc_generated_files/clc1.h"
#include "mcc_generated_files/interrupt_manager.h"
#include "mcc_generated_files/pin_manager.h"

#define ST_OFF					0x86	// stx(0)
#define ST_ON					0x84	// sty(2)
#define ADDR_RIGHT_LINE			0x3e
#define ADDR_END_LINES			0xb7

// I/O mappings
#define SET_DATA(X)     { LATB = (X); }
#define READ_DATA()     PORTB
#define DATA_OUTPUT     TRISB = 0x0000;
#define DATA_INPUT      TRISB = 0xffff;
#define DATA_OUTPUT_DIR IO_RA3_SetLow();
#define DATA_INPUT_DIR  IO_RA3_SetHigh();
#define LO_ADDRESS      (PORTC & 0x1FF)
#define LO_ADDRESS_FULL (PORTC)

#define EMULATE_DONE \
    { \
    CNFC = 0; /* clear all flags */     \
    IFS1bits.CNCIF = 0; /* clear flag */    \
    return; \
    }


// 

extern void				flash_led(uint8_t num);
__attribute__((section(".coreInfo"))) struct coreInfo			r_coreInfo;

// - - - - - - - - - - - - - - - - - - - - - - - - - - - - - - - - - - - - - -
void
coreInit()
{
	r_coreInfo.mr_endFrame = 1;
	r_coreInfo.mr_bufferIndex = false;

	r_coreInfo.mr_swcha = 0xff;
	r_coreInfo.mr_swchb = 0xff;
	r_coreInfo.mr_inpt4 = 0xff;
	r_coreInfo.mr_inpt5 = 0xff;	// not used

	r_coreInfo.peekBus = 0xff;
	r_coreInfo.storeAddress = &r_coreInfo.peekBus;

	r_coreInfo.breakLoops = 255;	// break 255 times before starting main frame loop

	r_coreInfo.lines = 190;

	r_coreInfo.hiAddress = 0xf0;
	r_coreInfo.vblankState = ST_OFF;
	r_coreInfo.vsyncState = ST_OFF;
	r_coreInfo.endState = 0;
	r_coreInfo.nextLineJump = ADDR_RIGHT_LINE;
	r_coreInfo.data = 0;

	DATA_OUTPUT_DIR;
	DATA_OUTPUT;

	// get this started as soon as possible
	PIN_MANAGER_enableInterrupt_On_Change();
}


// - - - - - - - - - - - - - - - - - - - - - - - - - - - - - - - - - - - - - -

void __attribute__((interrupt, no_auto_psv, context)) _CNCInterrupt(void)
{
	static const void* const romData[512] = 
	{
		&&gstore, &&gstore, &&gstore, &&gstore, &&gstore, &&gstore, &&gstore, &&gstore, &&gstore, &&gstore, &&gstore, &&gstore, &&gstore, &&gstore, &&gstore, &&gstore,
		&&gstore, &&gstore, &&gstore, &&gstore, &&gstore, &&gstore, &&gstore, &&gstore, &&gstore, &&gstore, &&gstore, &&gstore, &&gstore, &&gstore, &&gstore, &&gstore,
		&&gstore, &&gstore, &&gstore, &&gstore, &&gstore, &&gstore, &&gstore, &&gstore, &&gstore, &&gstore, &&gstore, &&gstore, &&gstore, &&gstore, &&gstore, &&gstore,
		&&gstore, &&gstore, &&gstore, &&gstore, &&gstore, &&gstore, &&gstore, &&gstore, &&gstore, &&gstore, &&gstore, &&gstore, &&gstore, &&gstore, &&gstore, &&gstore,
		&&gstore, &&gstore, &&gstore, &&gstore, &&gstore, &&gstore, &&gstore, &&gstore, &&gstore, &&gstore, &&gstore, &&gstore, &&gstore, &&gstore, &&gstore, &&gstore,
		&&gstore, &&gstore, &&gstore, &&gstore, &&gstore, &&gstore, &&gstore, &&gstore, &&gstore, &&gstore, &&gstore, &&gstore, &&gstore, &&gstore, &&gstore, &&gstore,
		&&gstore, &&gstore, &&gstore, &&gstore, &&gstore, &&gstore, &&gstore, &&gstore, &&gstore, &&gstore, &&gstore, &&gstore, &&gstore, &&gstore, &&gstore, &&gstore,
		&&gstore, &&gstore, &&gstore, &&gstore, &&gstore, &&gstore, &&gstore, &&gstore, &&gstore, &&gstore, &&gstore, &&gstore, &&gstore, &&gstore, &&gstore, &&gstore,
		&&gstore, &&gstore, &&gstore, &&gstore, &&gstore, &&gstore, &&gstore, &&gstore, &&gstore, &&gstore, &&gstore, &&gstore, &&gstore, &&gstore, &&gstore, &&gstore,
		&&gstore, &&gstore, &&gstore, &&gstore, &&gstore, &&gstore, &&gstore, &&gstore, &&gstore, &&gstore, &&gstore, &&gstore, &&gstore, &&gstore, &&gstore, &&gstore,
		&&gstore, &&gstore, &&gstore, &&gstore, &&gstore, &&gstore, &&gstore, &&gstore, &&gstore, &&gstore, &&gstore, &&gstore, &&gstore, &&gstore, &&gstore, &&gstore,
		&&gstore, &&gstore, &&gstore, &&gstore, &&gstore, &&gstore, &&gstore, &&gstore, &&gstore, &&gstore, &&gstore, &&gstore, &&gstore, &&gstore, &&gstore, &&gstore,
		&&gstore, &&gstore, &&gstore, &&gstore, &&gstore, &&gstore, &&gstore, &&gstore, &&gstore, &&gstore, &&gstore, &&gstore, &&gstore, &&gstore, &&gstore, &&gstore,
		&&gstore, &&gstore, &&gstore, &&gstore, &&gstore, &&gstore, &&gstore, &&gstore, &&gstore, &&gstore, &&gstore, &&gstore, &&gstore, &&gstore, &&gstore, &&gstore,
		&&gstore, &&gstore, &&gstore, &&gstore, &&gstore, &&gstore, &&gstore, &&gstore, &&gstore, &&gstore, &&gstore, &&gstore, &&gstore, &&gstore, &&gstore, &&gstore,
		&&gstore, &&gstore, &&gstore, &&gstore, &&gstore, &&gstore, &&gstore, &&gstore, &&gstore, &&gstore, &&gstore, &&gstore, &&gstore, &&gstore, &&gstore, &&gstore,

		&&g0x00, &&g0x01, &&g0x02, &&g0x03, &&g0x04, &&g0x05, &&g0x06, &&g0x07, &&g0x08, &&g0x09, &&g0x0a, &&g0x0b, &&g0x0c, &&g0x0d, &&g0x0e, &&g0x0f,
		&&g0x10, &&g0x11, &&g0x12, &&g0x13, &&g0x14, &&g0x15, &&g0x16, &&g0x17, &&g0x18, &&g0x19, &&g0x1a, &&g0x1b, &&g0x1c, &&g0x1d, &&g0x1e, &&g0x1f,
		&&g0x20, &&g0x21, &&g0x22, &&g0x23, &&g0x24, &&g0x25, &&g0x26, &&g0x27, &&g0x28, &&g0x29, &&g0x2a, &&g0x2b, &&g0x2c, &&g0x2d, &&g0x2e, &&g0x2f,
		&&g0x30, &&g0x31, &&g0x32, &&g0x33, &&g0x34, &&g0x35, &&g0x36, &&g0x37, &&g0x38, &&g0x39, &&g0x3a, &&g0x3b, &&g0x3c, &&g0x3d, &&g0x3e, &&g0x3f,
		&&g0x40, &&g0x41, &&g0x42, &&g0x43, &&g0x44, &&g0x45, &&g0x46, &&g0x47, &&g0x48, &&g0x49, &&g0x4a, &&g0x4b, &&g0x4c, &&g0x4d, &&g0x4e, &&g0x4f,
		&&g0x50, &&g0x51, &&g0x52, &&g0x53, &&g0x54, &&g0x55, &&g0x56, &&g0x57, &&g0x58, &&g0x59, &&g0x5a, &&g0x5b, &&g0x5c, &&g0x5d, &&g0x5e, &&g0x5f,
		&&g0x60, &&g0x61, &&g0x62, &&g0x63, &&g0x64, &&g0x65, &&g0x66, &&g0x67, &&g0x68, &&g0x69, &&g0x6a, &&g0x6b, &&g0x6c, &&g0x6d, &&g0x6e, &&g0x6f,
		&&g0x70, &&g0x71, &&g0x72, &&g0x73, &&g0x74, &&g0x75, &&g0x76, &&g0x77, &&g0x78, &&g0x79, &&g0x7a, &&g0x7b, &&g0x7c, &&g0x7d, &&g0x7e, &&g0x7f,
		&&g0x80, &&g0x81, &&g0x82, &&g0x83, &&g0x84, &&g0x85, &&g0x86, &&g0x87, &&g0x88, &&g0x89, &&g0x8a, &&g0x8b, &&g0x8c, &&g0x8d, &&g0x8e, &&g0x8f,
		&&g0x90, &&g0x91, &&g0x92, &&g0x93, &&g0x94, &&g0x95, &&g0x96, &&g0x97, &&g0x98, &&g0x99, &&g0x9a, &&g0x9b, &&g0x9c, &&g0x9d, &&g0x9e, &&g0x9f,
		&&g0xa0, &&g0xa1, &&g0xa2, &&g0xa3, &&g0xa4, &&g0xa5, &&g0xa6, &&g0xa7, &&g0xa8, &&g0xa9, &&g0xaa, &&g0xab, &&g0xac, &&g0xad, &&g0xae, &&g0xaf,
		&&g0xb0, &&g0xb1, &&g0xb2, &&g0xb3, &&g0xb4, &&g0xb5, &&g0xb6, &&g0xb7, &&g0xb8, &&g0xb9, &&g0xba, &&g0xbb, &&g0xbc, &&g0xbd, &&g0xbe, &&g0xbf,
		&&g0xc0, &&g0xc1, &&g0xc2, &&g0xc3, &&g0xc4, &&g0xc5, &&g0xc6, &&g0xc7, &&g0xc8, &&g0xc9, &&g0xca, &&g0xcb, &&g0xcc, &&g0xcd, &&g0xce, &&g0xcf,
		&&g0xd0, &&g0xd1, &&g0xd2, &&g0xd3, &&g0xd4, &&g0xd5, &&g0xd6, &&g0xd7, &&g0xd8, &&g0xd9, &&g0xda, &&g0xdb, &&g0xdc, &&g0xdd, &&g0xde, &&g0xdf,
		&&g0xe0, &&g0xe1, &&g0xe2, &&g0xe3, &&g0xe4, &&g0xe5, &&g0xe6, &&g0xe7, &&g0xe8, &&g0xe9, &&g0xea, &&g0xeb, &&g0xec, &&g0xed, &&g0xee, &&g0xef,
		&&g0xf0, &&g0xf1, &&g0xf2, &&g0xf3, &&g0xf4, &&g0xf5, &&g0xf6, &&g0xf7, &&g0xf8, &&g0xf9, &&g0xfa, &&g0xfb, &&g0xfc, &&g0xfd, &&g0xfe, &&g0xff
	};

   
    if (CLC1CONLbits.LCOUT)
    {
        EMULATE_DONE
    }

	goto *romData[LO_ADDRESS];
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

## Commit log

2021-03-11 initial software/hardware
    [Bom_8238251.csv, atarimovie.brd, atarimovie.sch]
2021-03-12 sample output
2021-04-01 Movie output extention changed to '.mvc' Allow for composite test saving using 44100 Hz audio and mov extension.
2021-04-02 Changed frame format to ['M', 'V', 'C', 0 ] at the beginning of each field
2021-04-03 Fixed BOM to correct quantities.
    [Bom_2021_04_02.csv, Bom_8238251.csv]
2021-04-04 Replaced microcontroller-centric implementation with full C++ version.
    [core.c]
2021-04-04 Fixed small ICSP labels on circuit reorganized output folder
    [atarimovie.brd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]
2021-04-23 Added more sample movies.
2021-04-25 Removed unnecessary reordering (and un-reordering) of color data, as this no longer applies to the current kernel.
2021-04-25 Update Plugin to latest version. Download texture immediately, not next frame. Adding OSX version
2021-06-02 Implement kernel format1 for microcontroller
    -Fixes vertical lines artifacts
    [core.c, sd_reader.c]
2021-06-03 Using PIC18F47K42 not PIC18F45K42
    [atarimovie.brd, atarimovie.sch]
2021-06-11 Fixed stepping forward faster than stepping back
    [core.c]
2021-08-30 Testing colorize options: Clamp values (will likely always On) Background (background color scanline search)
2021-09-11 - Make clamping default behaviour
2021-09-14 - removed unneeded Path + Weight parameters (test case: 235 ms -> 196 ms)
2021-09-19 - Preview slider should always land on odd frame to ensure plugin update
2021-10-02 - Begin with background color search with best result from previous frame (Andrew Davie)
2021-10-02 Add Frame milliseconds to output. Only trail for 2 seconds to get average.
2021-10-03 one decimal place for frame milliseconds
2021-12-29 pic code now up to date with latest encoding and playback changes background color support misc fixes for single stepping and OSD array bounds
    [core.c, sd_reader.c]
2023-09-23 Main improvements:
    - Replaced bulky expensive obsolete through-hole IC's with modern SMD components
    which can be fully created by PCB assembly houses.
    - Drop in compatible with Combat cartridges. No cutting / drilling / gluing required.
    - Micro SD Card uses standard FAT file format, so standard copy / drag-n-drop of files works.
    No longer requires separate utility to prepare card and playback no longer experiences
    random noise
    - Supports both NTSC and PAL formats.
    - Enhanced video quality utilizing TIA background and playfield colors and
    optimized color space searches.
    - Reliable startup, as boot time is now 1.14 msec
    (Flashback 2 boot time is 1.52 msec, while Atar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
    [Bom_2021_04_02.csv, atarimovie.brd, atarimovie.sch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]
2023-10-11 Refactor to support firmware upgrades
    splitting data+program usage into different sections
    using packed data for title screen
    avoiding debug stack memory
    boot time halved to 0.58msec by delaying all static initialization
    breakup main functions further for re-use
    [core.c, main.c]
2023-10-25 Don't lag crop when parked on a frame
2023-10-29 long playbar with separate play + record buttons
2023-10-29 playbar range tweaks and start/end from playbar buttons
2023-10-31 Reset-cancel no longer resets frame position.
2023-11-17 timecode is total recorded frames, not current index
2023-11-17 restore last recorded frame position when re-loading
2023-11-19 timeline range fix switching between pal + ntsc
2023-11-30 record button controls play button
2023-12-09 clamp last/first frame of movie when past ends. round up to nearest full frame for timeline
2023-12-29 Moving to gpu / shader based encoder
2023-12-31 show separate bits in intermediate stage curOffset should not reset each cell, but rather each line
2024-01-01 visually better with clamping at more stages
2024-01-03 stop running plugin at 60hz, run at 30hz and write 2 fields. simpler
2024-01-05 FramesInit redundant, save 2 bytes
2024-01-05 split firmware devices into two folders for easier swapping
2024-01-11 simulate compute shader for debugging
    [sample_input.tsv]
2024-01-16 testing multiple frames
2024-01-17 vsync off to not clamp at monitor rate
2024-01-19 implementing gpu/cpu encoder
    [sample_input.tsv]
2024-01-20 re-organized encoder interface parameters
2024-01-21 small interface improvements
    tidying audio network
    movie audio bargraph to playbar
    rewind to frame 1 when pressing play at end
    margin to right of parameters
    title: Movie Encoder
    fixed rewind to 5 seconds
    dont allow parameter expansion
    rearrange sections
    expose dither + bleed options
    reset controls resets most values as well
    erasefile built into start of final render
    stats button
2024-01-21 switching bool to bits to save memory
2024-02-16 PCB: slightly widened post hole from 3.175 to 3.210 mm
    [atarimovie.brd, atarimovie.sch]
2024-02-18 PCB: reduce the post radius closer to original: 3.175 -> 3.190
    Most boards still accepted the 1/4" post.
    [atarimovie.brd, atarimovie.sch]
2024-03-05 gerber files
2024-03-09 document potental patch for A12 7800 timing issues
    [main.c]
2024-03-12 interleaved sample kernel
2024-04-06 PAL, 7800 support
    Must select on A12(and)A11, not just A11, as A11 used by 7800.
    Kernel revised to avoid improper HMOVE that behaves badly on some TIA
    variants (Kool Aid Man fix), especially on PAL Jr's
    [core.c, main.c]
2024-04-21 avoid the title screen glitch when sampling the first frame for format PAL will still show NTSC for a few seconds before switching over
    [main.c]
2024-05-06 todo about hole sizes
2024-05-12 hole post notes
2024-05-15 board 2.32: hole size increased from 3.19 to 3.373
    [atarimovie.brd, atarimovie.sch]
2024-05-16 gerber files and rerouting away from post hole slightly
    [atarimovie.brd]
2024-05-20 SECAM should be 50Hz not 60Hz
2024-05-24 spaced out caddr8 caddr9 @LODEFMODE not LODEF.MODE
    [atarimovie.brd]
2024-06-30 injection molded shell notes firmware update notes
2024-07-05 LED too bright note
2024-09-11 patch1 : multifile support. cycle through files on the moviecart with 'SELECT' button.
2024-10-01 refer to updated parts library
    [atarimovie.sch]
2024-10-26 separate bootloader + kernel fixes
    separate bootloader section that contains FLASH
    and other utilities independent of regular main code
    No longer relies on exact memory locations.
    Wipe out full section and rewrite.
    Avoid writes to ROM
    PAL 7800: output consistent value for 7E00-7EFF to pass startup check
    [core.c, main.c]
2024-10-29 color_char bins for device testing
2025-05-10 write protect original firmware code (0x000 - 0x3FFF) new AIVT starts at 0x4000 (AIVT CNC at 0x5000) and new code checked at 0x4800 (all writable) other AIVT vectors left at default
    this allows original firmware to be safe from accidental updates, while
    still allowing udpates to define their own low-level interrupt based kernel.
2025-05-10 Sikor style PCB
    [atarimovie.brd, atarimovie.sch, atarimovie_top_bom.csv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]
2025-10-19 Reset switch -> rewind 10 seconds Select switch -> switch to next movie as before When movie ends, automatically start next movie.
2025-10-20 Full kernel patch to now play all mvc files sequentially on the SD card. This patch replaces the entire firmware, is permanent and can brick the card if not installed correctly. Use with caution.
    [main.c]
2025-10-21 fixed repeat error codes bumped internal eeprom version to 0202
    [main.c]
2025-12-26 patch fixes to not erase inside executing code. patch upgraded to 2.3
    [main.c]

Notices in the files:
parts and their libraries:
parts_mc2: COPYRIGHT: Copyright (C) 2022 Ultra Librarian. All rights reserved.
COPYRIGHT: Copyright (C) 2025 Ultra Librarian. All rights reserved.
